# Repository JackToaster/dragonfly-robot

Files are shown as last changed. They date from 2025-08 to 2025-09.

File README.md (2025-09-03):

# Dragonfly Robot
This repository contains hardware and firmware files for a flight controller & 4-channel servo driver, intended for my dragonfly ornithopter robot.

## Robot hardware
The robot is built from components 3d printed out of lightweight PLA and pulltruded carbon fiber rods, with two standard 3.7g RC servos actuating each wing.
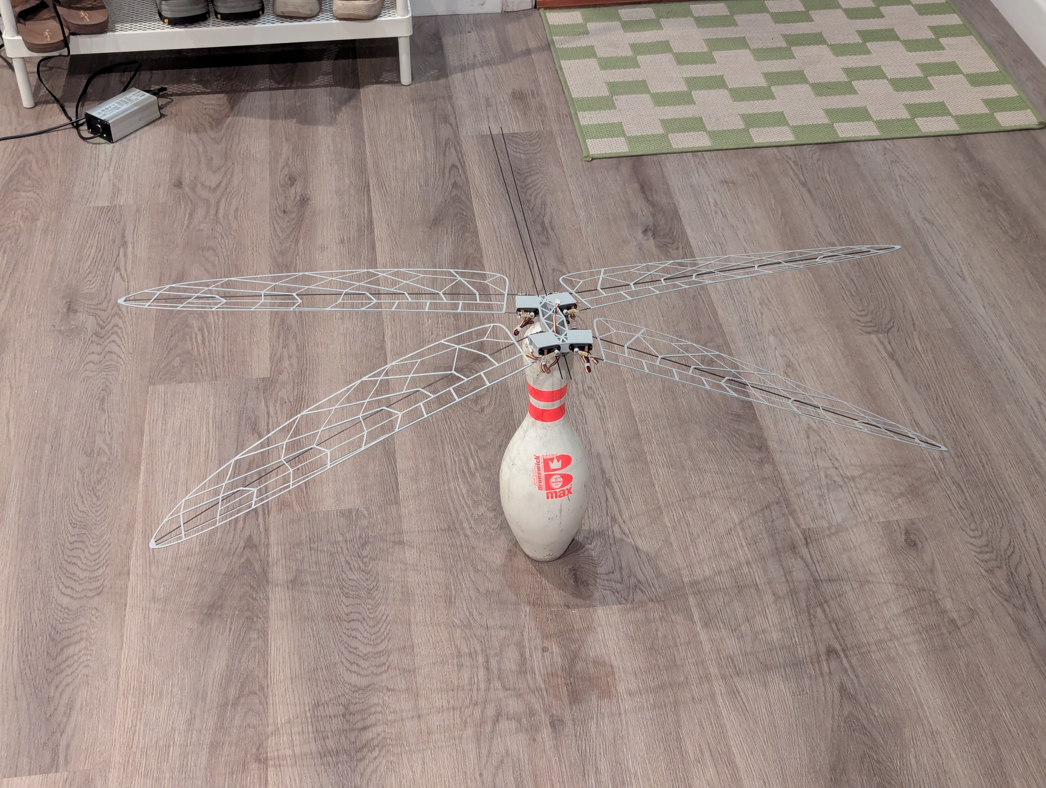
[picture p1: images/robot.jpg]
Dragonfly robot


## PCB
The flight controlelr hardware is based on the WCH CH32V203, a low-cost RISC-V microcontroller.
Motor drives use the TI DRV8212 full-bridge driver and INA199 current sense amplifier for current feedback.
Each controller drives one pair of wings (four actuators). The controllers for each wing pair communicate with each other via I2C. An I2C IMU (MPU6050/MPU9250) is used for attitude control, and an RC receiver is connected over a serial link via the CRSF protocol.
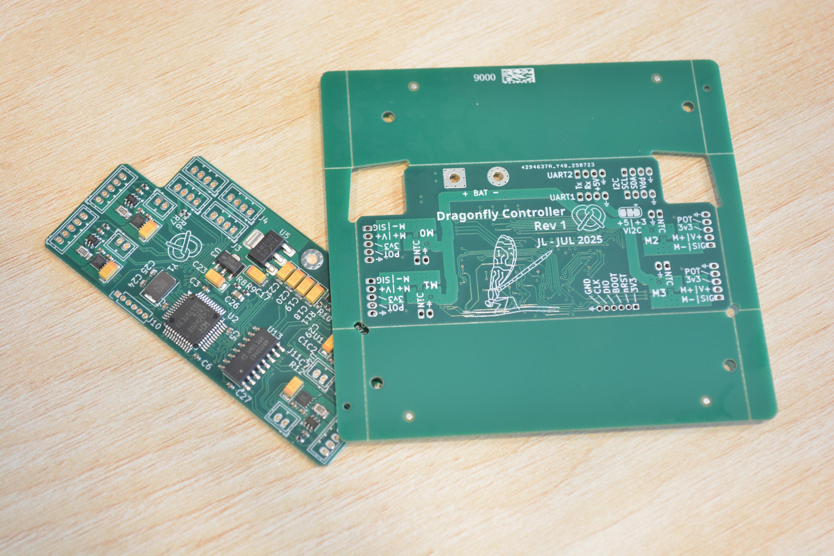
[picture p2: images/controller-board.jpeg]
Dragonfly robot controller PCB


## Firmware
The firmware in this repository utilizes CNLohr's [CH32Fun](https://github.com/cnlohr/ch32fun) framework for register mapping and hardware initialization functionality.

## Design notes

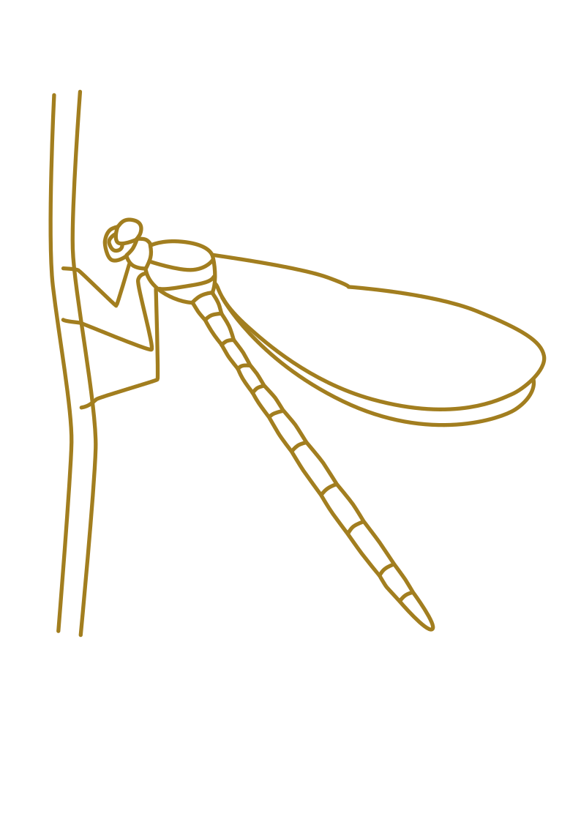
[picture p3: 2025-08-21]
servo-drive/dragonfly.png

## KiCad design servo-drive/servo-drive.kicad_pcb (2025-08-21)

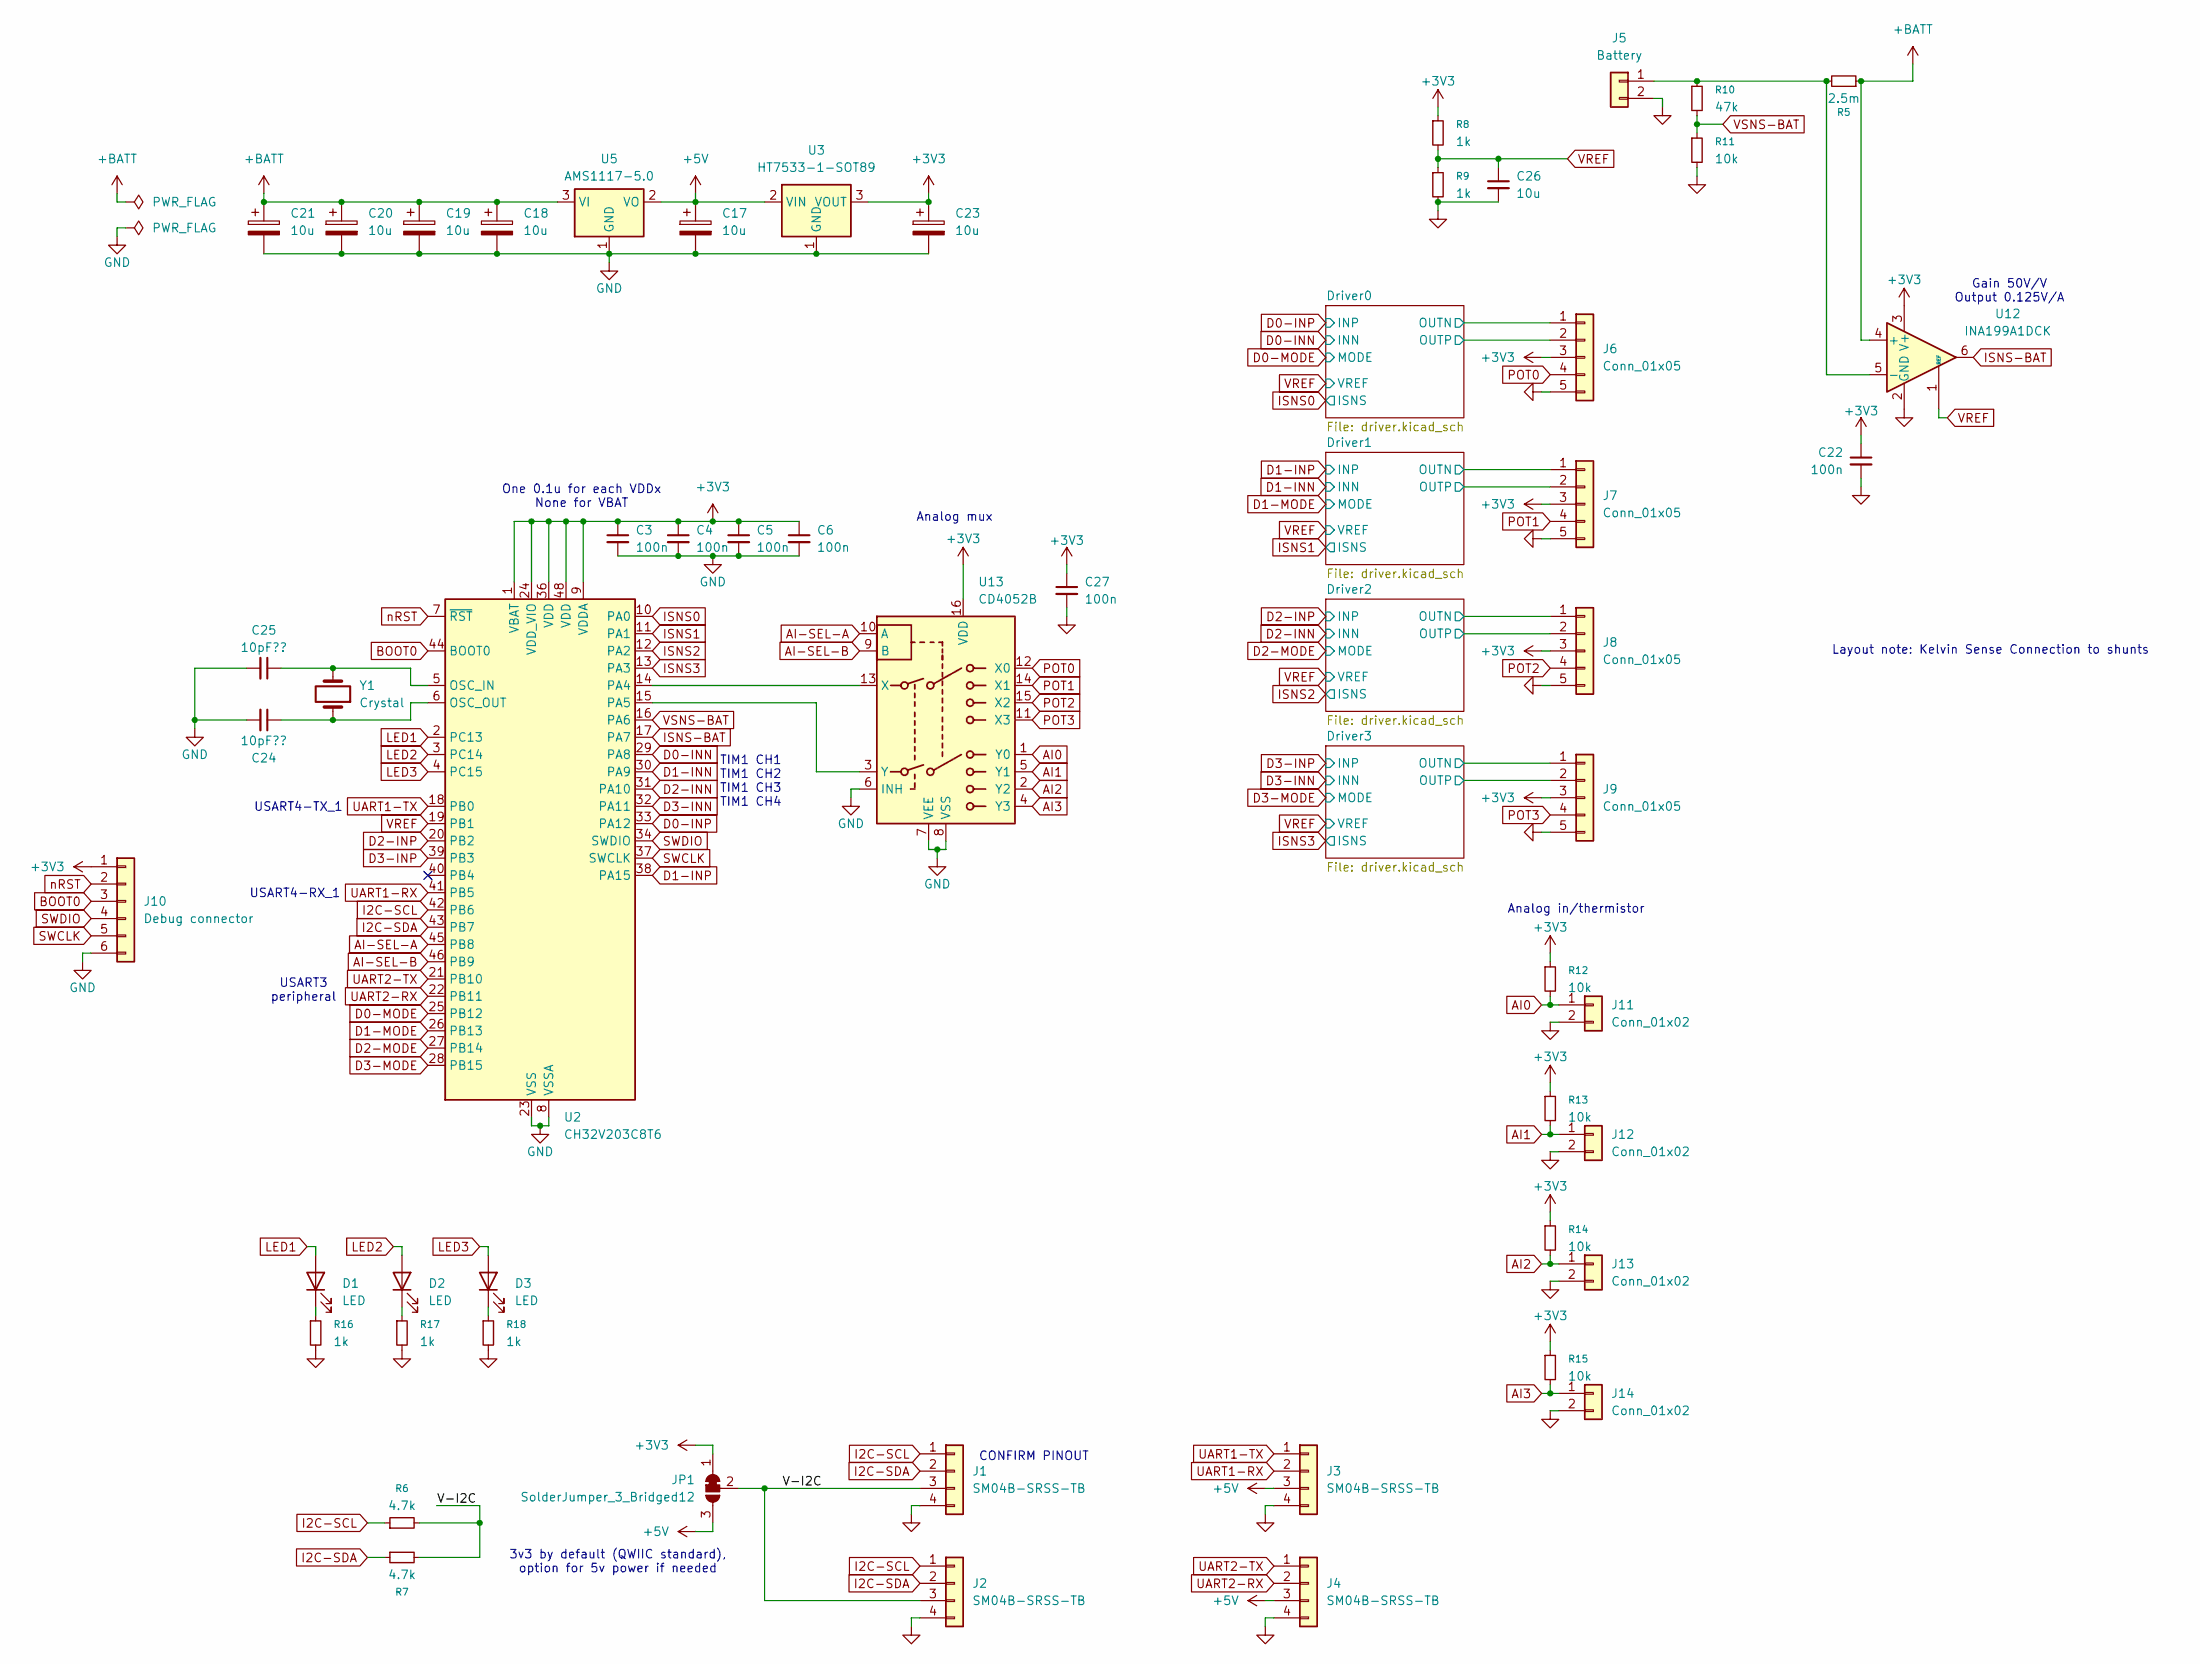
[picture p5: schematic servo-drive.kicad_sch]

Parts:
C3, C4, C5, C6, C22, C27: 100n; C_0402_1005Metric; LCSC C307331
C17, C18, C19, C20, C21, C23: 10u; CP_EIA-3216-18_Kemet-A; LCSC C7171
C24, C25: 10pF??; C_0402_1005Metric; LCSC C32949
C26: 10u; C_0603_1608Metric; LCSC C19702
D1, D2, D3: LED; LED_0603_1608Metric_Pad1.05x0.95mm_HandSolder
J1, J2, J3, J4: SM04B-SRSS-TB; JST_ZH_B4B-ZR_1x04_P1.50mm_Vertical
J5: Battery; SolderWire-1sqmm_1x02_P7.8mm_D1.4mm_OD3.9mm
J6, J7, J8, J9: Conn_01x05; JST_ZH_B5B-ZR_1x05_P1.50mm_Vertical
J10: Debug connector; PinHeader_1x06_P1.27mm_Vertical
J11, J12, J13, J14: Conn_01x02; JST_ZH_B2B-ZR_1x02_P1.50mm_Vertical
JP1: SolderJumper_3_Bridged12; SolderJumper-3_P1.3mm_Bridged12_RoundedPad1.0x1.5mm
R5: 2.5m; R_0805_2012Metric; LCSC C728266
R6, R7: 4.7k; R_0402_1005Metric; LCSC C25900
R8, R9, R16, R17, R18: 1k; R_0402_1005Metric; LCSC C11702
R10: 47k; R_0402_1005Metric; LCSC C25792
R11, R12, R13, R14, R15: 10k; R_0402_1005Metric; LCSC C25744
U2: CH32V203C8T6; LQFP-48_7x7mm_P0.5mm; LCSC C3001172
U3: HT7533-1-SOT89; SOT-89-3; LCSC C14289
U5: AMS1117-5.0; SOT-223-3_TabPin2; LCSC C6187
U12: INA199A1DCK; SOT-363_SC-70-6; LCSC C2653849
U13: CD4052B; SOIC-16_3.9x9.9mm_P1.27mm; LCSC C6521
Y1: Crystal; Crystal_SMD_5032-2Pin_5.0x3.2mm; LCSC C115962

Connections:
+3V3: C3.1, C4.1, C5.1, C6.1, C22.1, C23.1, C27.1, J6.3, J7.3, J8.3, J9.3, J10.1, JP1.1 (A), R8.1, R12.1, R13.1, R14.1, R15.1, U2.1 (VBAT), U2.9 (VDDA), U2.24 (VDD_VIO), U2.36 (VDD), U2.48 (VDD), U3.3 (VOUT), U12.3 (V+), U13.16 (VDD); also elsewhere on the board
+5V: C17.1, J3.3, J4.3, JP1.3 (B), U3.2 (VIN), U5.2 (VO)
+BATT: C18.1, C19.1, C20.1, C21.1, R5.1, U5.3 (VI), U12.4 (+); also elsewhere on the board
/Driver0/OUTN: J6.1; also elsewhere on the board
/Driver0/OUTP: J6.2; also elsewhere on the board
/Driver1/OUTN: J7.1; also elsewhere on the board
/Driver1/OUTP: J7.2; also elsewhere on the board
/Driver2/OUTN: J8.1; also elsewhere on the board
/Driver2/OUTP: J8.2; also elsewhere on the board
/Driver3/OUTN: J9.1; also elsewhere on the board
/Driver3/OUTP: J9.2; also elsewhere on the board
/V-I2C: J1.3, J2.3, JP1.2 (C), R6.2, R7.2
AI0: J11.1, R12.2, U13.1 (Y0)
AI1: J12.1, R13.2, U13.5 (Y1)
AI2: J13.1, R14.2, U13.2 (Y2)
AI3: J14.1, R15.2, U13.4 (Y3)
AI-SEL-A: U2.45 (PB8), U13.10 (A)
AI-SEL-B: U2.46 (PB9), U13.9 (B)
BOOT0: J10.3, U2.44 (BOOT0)
D0-INN: U2.29 (PA8); also elsewhere on the board
D0-INP: U2.33 (PA12); also elsewhere on the board
D0-MODE: U2.25 (PB12); also elsewhere on the board
D1-INN: U2.30 (PA9); also elsewhere on the board
D1-INP: U2.38 (PA15); also elsewhere on the board
D1-MODE: U2.26 (PB13); also elsewhere on the board
D2-INN: U2.31 (PA10); also elsewhere on the board
D2-INP: U2.20 (PB2); also elsewhere on the board
D2-MODE: U2.27 (PB14); also elsewhere on the board
D3-INN: U2.32 (PA11); also elsewhere on the board
D3-INP: U2.39 (PB3); also elsewhere on the board
D3-MODE: U2.28 (PB15); also elsewhere on the board
GND: C3.2, C4.2, C5.2, C6.2, C17.2, C18.2, C19.2, C20.2, C21.2, C22.2, C23.2, C24.2, C25.2, C26.2, C27.2, J1.4, J2.4, J3.4, J4.4, J5.2, J6.5, J7.5, J8.5, J9.5, J10.6, J11.2, J12.2, J13.2, J14.2, R9.2, R11.2, R16.2, R17.2, R18.2, U2.8 (VSSA), U2.23 (VSS), U2.35 (VSS), U2.47 (VSS), U3.1 (GND), U5.1 (GND), U12.2 (GND), U13.6 (INH), U13.7 (VEE), U13.8 (VSS); also elsewhere on the board
I2C-SCL: J1.1, J2.1, R6.1, U2.42 (PB6)
I2C-SDA: J1.2, J2.2, R7.1, U2.43 (PB7)
ISNS0: U2.10 (PA0); also elsewhere on the board
ISNS1: U2.11 (PA1); also elsewhere on the board
ISNS2: U2.12 (PA2); also elsewhere on the board
ISNS3: U2.13 (PA3); also elsewhere on the board
ISNS-BAT: U2.17 (PA7), U12.6
LED1: D1.2 (A), U2.2 (PC13)
LED2: D2.2 (A), U2.3 (PC14)
LED3: D3.2 (A), U2.4 (PC15)
unnamed: D1.1 (K), R16.1
unnamed: D2.1 (K), R17.1
unnamed: D3.1 (K), R18.1
unnamed: J5.1, R5.2, R10.1, U12.5 (-)
unnamed: C25.1, U2.5 (OSC_IN), Y1.2
unnamed: C24.1, U2.6 (OSC_OUT), Y1.1
unnamed: U2.14 (PA4), U13.13 (X)
unnamed: U2.15 (PA5), U13.3 (Y)
POT0: J6.4, U13.12 (X0)
POT1: J7.4, U13.14 (X1)
POT2: J8.4, U13.15 (X2)
POT3: J9.4, U13.11 (X3)
SWCLK: J10.5, U2.37 (SWCLK)
SWDIO: J10.4, U2.34 (SWDIO)
UART1-RX: J3.2, U2.41 (PB5)
UART1-TX: J3.1, U2.18 (PB0)
UART2-RX: J4.2, U2.22 (PB11)
UART2-TX: J4.1, U2.21 (PB10)
VREF: C26.1, R8.2, R9.1, U2.19 (PB1), U12.1 (REF); also elsewhere on the board
VSNS-BAT: R10.2, R11.1, U2.16 (PA6)
nRST: J10.2, U2.7 (~RST)

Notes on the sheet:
Analog mux
USART4-TX_1
Analog in/thermistor
USART4-RX_1
Gain 50V/V Output 0.125V/A
Layout note: Kelvin Sense Connection to shunts
CONFIRM PINOUT
One 0.1u for each VDDx None for VBAT
3v3 by default (QWIIC standard), option for 5v power if needed
USART3 peripheral
TIM1 CH1 TIM1 CH2 TIM1 CH3 TIM1 CH4

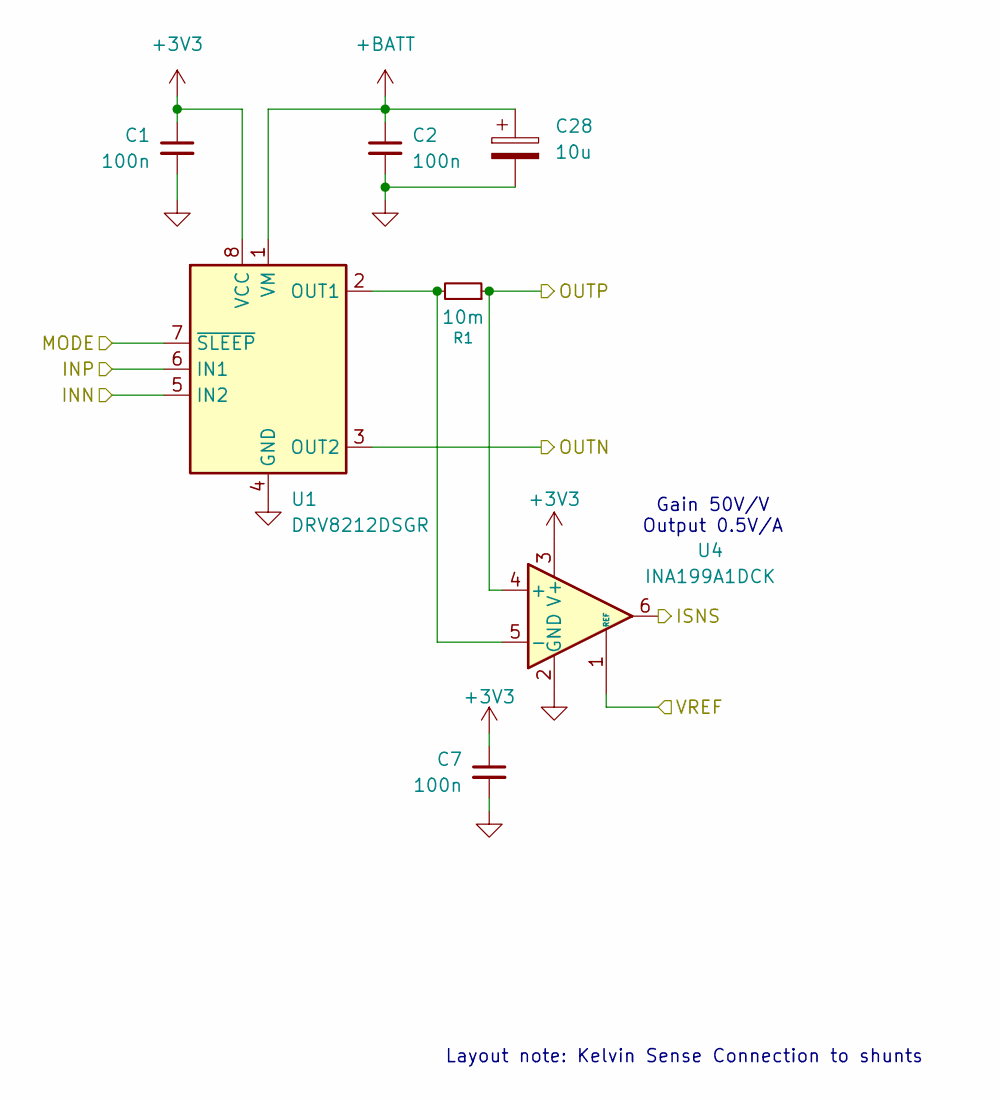
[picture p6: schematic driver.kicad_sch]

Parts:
C1, C2, C7: 100n; C_0402_1005Metric; LCSC C307331
C28: 10u; CP_EIA-3216-18_Kemet-A; LCSC C7171
R1: 10m; R_0805_2012Metric; LCSC C104574
U1: DRV8212DSGR; WSON-8-1EP_2x2mm_P0.5mm_EP0.9x1.6mm_ThermalVias; LCSC C2843766
U4: INA199A1DCK; SOT-363_SC-70-6; LCSC C2653849

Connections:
+3V3: C1.1, C7.1, U1.8 (VCC), U4.3 (V+); also elsewhere on the board
+BATT: C2.1, C28.1, U1.1 (VM); also elsewhere on the board
/Driver0/OUTN: U1.3 (OUT2); also elsewhere on the board
/Driver0/OUTP: R1.1, U4.4 (+); also elsewhere on the board
D0-INN: U1.5 (IN2); also elsewhere on the board
D0-INP: U1.6 (IN1); also elsewhere on the board
D0-MODE: U1.7 (~SLEEP); also elsewhere on the board
GND: C1.2, C2.2, C7.2, C28.2, U1.4 (GND), U1.9 (GND), U4.2 (GND); also elsewhere on the board
ISNS0: U4.6; also elsewhere on the board
unnamed: R1.2, U1.2 (OUT1), U4.5 (-)
VREF: U4.1 (REF); also elsewhere on the board

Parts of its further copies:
C8, C9, C10, C11, C12, C13, C14, C15, C16: 100n; C_0402_1005Metric; LCSC C307331
C29, C30, C31: 10u; CP_EIA-3216-18_Kemet-A; LCSC C7171
R2, R3, R4: 10m; R_0805_2012Metric; LCSC C104574
U6, U8, U10: DRV8212DSGR; WSON-8-1EP_2x2mm_P0.5mm_EP0.9x1.6mm_ThermalVias; LCSC C2843766
U7, U9, U11: INA199A1DCK; SOT-363_SC-70-6; LCSC C2653849

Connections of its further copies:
+3V3: C8.1, C10.1, C11.1, C13.1, C14.1, C16.1, U6.8 (VCC), U7.3 (V+), U8.8 (VCC), U9.3 (V+), U10.8 (VCC), U11.3 (V+); also elsewhere on the board
+BATT: C9.1, C12.1, C15.1, C29.1, C30.1, C31.1, U6.1 (VM), U8.1 (VM), U10.1 (VM); also elsewhere on the board
/Driver1/OUTN: U6.3 (OUT2); also elsewhere on the board
/Driver1/OUTP: R2.1, U7.4 (+); also elsewhere on the board
/Driver2/OUTN: U8.3 (OUT2); also elsewhere on the board
/Driver2/OUTP: R3.1, U9.4 (+); also elsewhere on the board
/Driver3/OUTN: U10.3 (OUT2); also elsewhere on the board
/Driver3/OUTP: R4.1, U11.4 (+); also elsewhere on the board
D1-INN: U6.5 (IN2); also elsewhere on the board
D1-INP: U6.6 (IN1); also elsewhere on the board
D1-MODE: U6.7 (~SLEEP); also elsewhere on the board
D2-INN: U8.5 (IN2); also elsewhere on the board
D2-INP: U8.6 (IN1); also elsewhere on the board
D2-MODE: U8.7 (~SLEEP); also elsewhere on the board
D3-INN: U10.5 (IN2); also elsewhere on the board
D3-INP: U10.6 (IN1); also elsewhere on the board
D3-MODE: U10.7 (~SLEEP); also elsewhere on the board
GND: C8.2, C9.2, C10.2, C11.2, C12.2, C13.2, C14.2, C15.2, C16.2, C29.2, C30.2, C31.2, U6.4 (GND), U6.9 (GND), U7.2 (GND), U8.4 (GND), U8.9 (GND), U9.2 (GND), U10.4 (GND), U10.9 (GND), U11.2 (GND); also elsewhere on the board
ISNS1: U7.6; also elsewhere on the board
ISNS2: U9.6; also elsewhere on the board
ISNS3: U11.6; also elsewhere on the board
unnamed: R2.2, U6.2 (OUT1), U7.5 (-)
unnamed: R3.2, U8.2 (OUT1), U9.5 (-)
unnamed: R4.2, U10.2 (OUT1), U11.5 (-)
VREF: U7.1 (REF), U9.1 (REF), U11.1 (REF); also elsewhere on the board

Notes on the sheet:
Gain 50V/V Output 0.5V/A
Layout note: Kelvin Sense Connection to shunts

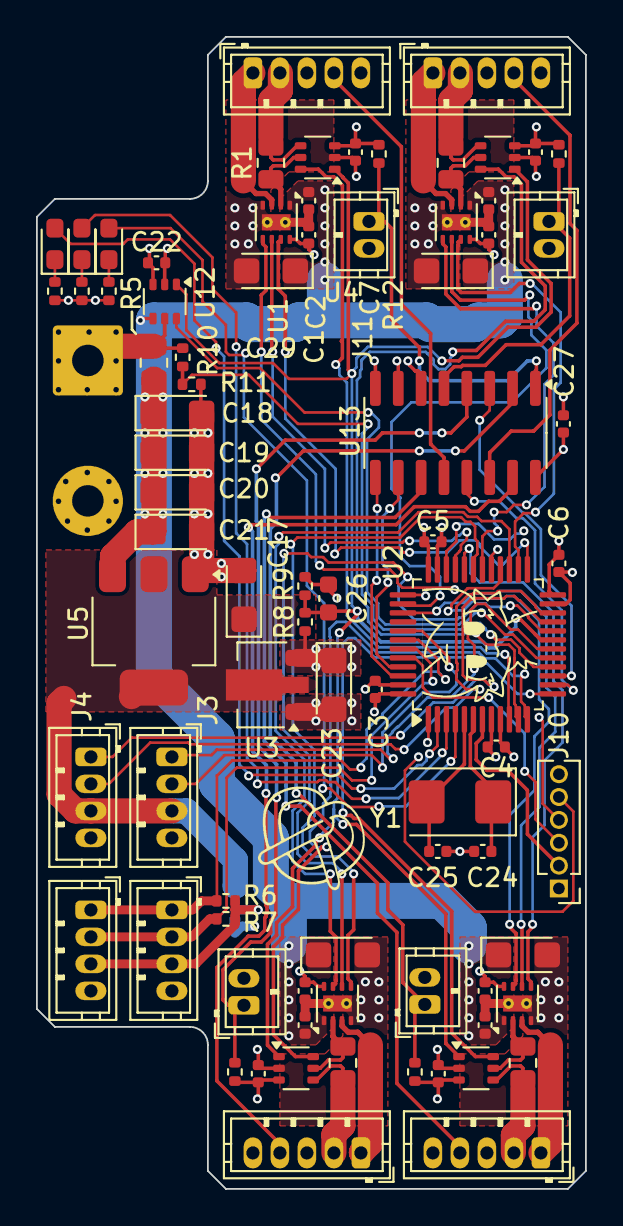
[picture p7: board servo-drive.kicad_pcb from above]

Board: 4 copper layers, 30.5 x 64.0 mm, 81 parts (1 on the bottom side), 67 nets.

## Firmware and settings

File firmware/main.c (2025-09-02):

#include "ch32fun.h"
#include <stdint.h>
#include <stdio.h>
#include "ch32v20xhw.h"

#include "main.h"
#include "led_status.h"
#include "adc.h"
#include "serial.h"
#include "systick.h"
#include "motor.h"
#include "crsf.h"

// Debug printf
uint32_t count;

int last = 0;
void handle_debug_input( int numbytes, uint8_t * data )
{
	last = data[0];
	count += numbytes;
}


// LED indicator state
LedStateT status_led_state;

uint32_t get_vbat( void ){
	return (uint32_t) adc_state.vsns_bat * ADC_VDD_mV / ADC_COUNTS * 57 / 10 ;
}


uint8_t adc_sel_no = 0;
void system_update( void ) {


	led_status_process(&status_led_state);
	// start polling new adc data
	adc_poll_dma();
	adc_wait_for_data();
	// read last data
	adc_process_data();

	motor_update(); // update motor control loops

	++adc_sel_no;
	if(adc_sel_no >= 4) { adc_sel_no = 0; }
	adc_ai_select(adc_sel_no);
}

int main()
{
	SystemInit();

	// APB2 clock /2 (72MHz)
	RCC->CFGR0 |= RCC_PPRE2_DIV2;

	funGpioInitAll(); // Enable GPIOs

	// MCO for clock debugging
	// RCC->CFGR0 |= RCC_CFGR0_MCO_SYSCLK;


	funPinMode(AI_SEL_A, GPIO_CFGLR_OUT_10Mhz_PP);
	funPinMode(AI_SEL_B, GPIO_CFGLR_OUT_10Mhz_PP);

	// initializing peripherals
	status_led_state = led_status_init();

	crc_init();

	// Serial
	printf("starting serial...\n");
	serial_init();
	dma_uart_setup();
	printf("Serial up\n");

	// ADC
	printf("starting ADC...\n");
	adc_init();
	printf("ADC up\n");

	motor_init();

	// enable systick
	systick_init();
	uint8_t duty = 100;

	uint32_t last_t;
	uint32_t last_pos;

	for(uint8_t i = 0; i < N_MOTORS; ++i) {
		// motors[i].duty_cap = MOTOR_DUTY_MAX / 3; // 33% duty limit to avoid burning out servos while testing
	}

	wakeup_motors();
	// set_position(&motors[3], 1500);

	while(1)
	{
		Delay_Us(systick_remaining_us()); // wait for next tick

		// printf("M3 P:%d\n", adc_state.pot[3]);
		system_update();
	

		// if(millis() % 2000 == 0) {
		// 	set_position(&motors[3], 1900);
		// }
		// if(millis() % 2000 == 1000) {
		// 	set_position(&motors[3], 2100);
		// }
		// printf("%d\n", adc_state.pot[3]);
		// https://github.com/crsf-wg/crsf/wiki/Message-Format
		uint8_t bytes;
		while((bytes = bytes_available(&uart3_rxbuf)) >= 4) { // minimum size for CSRF message is 4 bytes
			uint8_t sync = peek(&uart3_rxbuf);
			if(sync == 0xC8 || sync == 0xEE) { // check for CRSF Sync byte
				uint8_t* header = peek_n(&uart3_rxbuf, 3);
				uint8_t msg_len = header[1] + 2; // message length is LEN+2
				if(msg_len > 64) {
					printf("I\n");//NVALID sync %x len %d :(((\n", sync, msg_len);
					
					read_data(&uart3_rxbuf, 1); // discard byte
					continue;
				}
				uint8_t msg_type = header[2];
				if(bytes >= msg_len) {
					// printf("msg! len %d type %x\n", msg_len, msg_type);
					uint8_t* message = read_data(&uart3_rxbuf, msg_len);
					uint8_t crc = crc8x_fast(0, &message[2], msg_len - 3);
					uint8_t msg_crc = message[msg_len - 1];
					if(crc != msg_crc) {
						printf("crc er %x %x\n", crc, msg_crc);
						continue;
					}
					if(msg_type == 0x16) { // RC channels packed
						
						// printf("Computed %x msg %x\n", crc, msg_crc);
						struct crsf_channels_s* channels = (struct crsf_channels_s*) &message[3];


						// printf("Channels %u %u %u %u %u %u %u %u %u %u %u %u %u %u %u %u\n", channels->ch0,channels->ch1,channels->ch2,channels->ch3,channels->ch4,channels->ch5,channels->ch6,channels->ch7,channels->ch8,channels->ch9,channels->ch10,channels->ch11,channels->ch12,channels->ch13,channels->ch14,channels->ch15);
						// set_duty_pct(&motors[3], (((int32_t)channels->ch0) - 992) / 6);
						set_position(&motors[3], (int32_t)channels->ch0);
					}
				} else {
					break;
				}
			} else {
				// printf(":( %d\n", uart3_rxbuf.overrun);
				read_data(&uart3_rxbuf, 1); // discard byte
			}
		}
	}
}

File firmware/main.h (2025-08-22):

#pragma once
#include "adc.h"


#define ADC_VDD_mV 3300
#define MOTOR_ISNS_GAIN (1000/500) // mAmps/mVolt
#define BATTERY_ISNS_GAIN (1000/125) // mAmps/mVolt
#define BATTERY_VSNS_GAIN (57000/10) // mVolt/volt

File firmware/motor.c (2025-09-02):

#include "motor.h"
#include "adc.h"
#include "ch32fun.h"
#include "ch32v20xhw.h"
#include "systick.h"
#include <stdlib.h>

MotorCtrlT motors[N_MOTORS];

void motor_init( void ) {
	// init motors struct
	for(uint8_t i = 0; i < N_MOTORS; ++i){
		motors[i].duty = 0;
		motors[i].current_setpoint = 0;
		motors[i].current_integrator = 0;

		motors[i].position_setpoint = 2048; // midpoint
		motors[i].duty_cap = MOTOR_DUTY_MAX;
		motors[i].mode = MOTOR_DISABLED;
	}
	// motor pins/buffers
	motors[0].duty_buffer = &(TIM1->CH1CVR);
	motors[0].dir_pin = MOTOR_D0_DIR;

	motors[1].duty_buffer = &(TIM1->CH2CVR);
	motors[1].dir_pin = MOTOR_D2_DIR;

	motors[2].duty_buffer = &(TIM1->CH3CVR);
	motors[2].dir_pin = MOTOR_D2_DIR;

	motors[3].duty_buffer = &(TIM1->CH4CVR);
	motors[3].dir_pin = MOTOR_D3_DIR;

	// setup TIM1
	// enable TIM1
	RCC->APB2PCENR |= RCC_APB2Periph_TIM1;

	// Reset TIM1 to init all regs
	RCC->APB2PRSTR |= RCC_APB2Periph_TIM1;
	RCC->APB2PRSTR &= ~RCC_APB2Periph_TIM1;

	// CTLR1: default is up, events generated, edge align
	// SMCFGR: default clk input is CK_INT
	
	// Prescaler 
	// Using APB2 Bus x2 (72MHz x2 = 144MHz)
	TIM1->PSC = 0x0000;
	
	// Auto Reload - sets period
	TIM1->ATRLR = MOTOR_DUTY_MAX;
	
	// Reload immediately
	TIM1->SWEVGR |= TIM_UG;

	
	// Enable CH1-4 output, default polarity (High for 0-CCR, low after)
	TIM1->CCER |= TIM_CC1E | TIM_CC2E | TIM_CC3E | TIM_CC4E;
	
	// CH1/2 Mode is output, PWM1 (CC1S = 00, OC1M = 110)
	TIM1->CHCTLR1 |= TIM_OC1M_2 | TIM_OC1M_1 | TIM_OC2M_2 | TIM_OC2M_1;
	
	// CH3/4 Mode is output, PWM1 (CC1S = 00, OC1M = 110)
	TIM1->CHCTLR2 |= TIM_OC3M_2 | TIM_OC3M_1 | TIM_OC4M_2 | TIM_OC4M_1;
	
	// Set the Capture Compare Register value to 0 initially
	TIM1->CH1CVR = 0;
	TIM1->CH2CVR = 0;
	TIM1->CH3CVR = 0;
	TIM1->CH4CVR = 0;
	
	// Enable TIM1 outputs
	TIM1->BDTR |= TIM_MOE;
	
	// Enable TIM1
	TIM1->CTLR1 |= TIM_CEN;

	// Setup mode pins
	funPinMode( MOTOR_D0_MODE, GPIO_Speed_10MHz | GPIO_CNF_OUT_PP );
	funPinMode( MOTOR_D1_MODE, GPIO_Speed_10MHz | GPIO_CNF_OUT_PP );
	funPinMode( MOTOR_D2_MODE, GPIO_Speed_10MHz | GPIO_CNF_OUT_PP );
	funPinMode( MOTOR_D3_MODE, GPIO_Speed_10MHz | GPIO_CNF_OUT_PP );

	// MODE 1 PH/EN
	funDigitalWrite(MOTOR_D0_MODE, 1);
	funDigitalWrite(MOTOR_D1_MODE, 1);
	funDigitalWrite(MOTOR_D2_MODE, 1);
	funDigitalWrite(MOTOR_D3_MODE, 1);


	// set up enable pins (these get PWM'd)
	funPinMode( MOTOR_D0_EN, GPIO_Speed_10MHz | GPIO_CNF_OUT_PP_AF );
	funPinMode( MOTOR_D1_EN, GPIO_Speed_10MHz | GPIO_CNF_OUT_PP_AF );
	funPinMode( MOTOR_D2_EN, GPIO_Speed_10MHz | GPIO_CNF_OUT_PP_AF );
	funPinMode( MOTOR_D3_EN, GPIO_Speed_10MHz | GPIO_CNF_OUT_PP_AF );


	// Dir pins
	funPinMode( MOTOR_D0_DIR, GPIO_Speed_10MHz | GPIO_CNF_OUT_PP );
	funPinMode( MOTOR_D1_DIR, GPIO_Speed_10MHz | GPIO_CNF_OUT_PP );
	funPinMode( MOTOR_D2_DIR, GPIO_Speed_10MHz | GPIO_CNF_OUT_PP );
	funPinMode( MOTOR_D3_DIR, GPIO_Speed_10MHz | GPIO_CNF_OUT_PP );

	funDigitalWrite(MOTOR_D3_DIR, 0);
	funDigitalWrite(MOTOR_D3_DIR, 0);
	funDigitalWrite(MOTOR_D3_DIR, 0);
	funDigitalWrite(MOTOR_D3_DIR, 0);


}

uint8_t ditherer = 0;
void set_from_duty(MotorCtrlT * motor) {
	uint32_t pos_duty = abs(motor->duty);

	pos_duty += MOTOR_DUTY_MIN;  // duties less than this will make the DRV8212 fall asleep :'(
	// this means you can't go below 4% duty at 10kHz, 8% at 20kHz

	if(pos_duty > motor->duty_cap) {
		pos_duty = motor->duty_cap;
	}
	
	funDigitalWrite(motor->dir_pin, motor->duty > 0);
	*motor->duty_buffer = pos_duty;
}
void motor_update( void ) {
	ditherer = !ditherer; // toggle each time
	for(uint8_t i = 0; i < N_MOTORS; ++i) {
		if(motors[i].mode == MOTOR_DISABLED) {
			*motors[i].duty_buffer = 0; // will need to wake up again...
		}else if(motors[i].mode == MOTOR_DUTY_CYCLE) {
			set_from_duty(&motors[i]);
		}else if(motors[i].mode == MOTOR_CURRENT_CONTROL) { // TODO Current sensing borken :'(((
			int32_t current_feedback = adc_state.isns_motor[i]; // read & convert to int32

			#ifdef CURRENT_FEEDBACK_INVERTED
			current_feedback = -current_feedback; // invert if necessary
			#endif
			
			int32_t current_error = motors[i].current_setpoint - current_feedback;

			int32_t current_p = current_error * CURRENT_kP; // proportional term
			
			//integral term
			motors[i].current_integrator += current_error;

			int32_t current_i = motors[i].current_integrator * CURRENT_kI;
			if(current_i > CURRENT_GAIN_SCALE) { // anti-windup past limits of control
				motors[i].current_integrator = CURRENT_GAIN_SCALE / CURRENT_kI;
			} else if(current_i < -CURRENT_GAIN_SCALE) {
				motors[i].current_integrator = -(CURRENT_GAIN_SCALE / CURRENT_kI);
			}

			int32_t demand = current_p + current_i;
			motors[i].duty = (demand * MOTOR_DUTY_MAX) / CURRENT_GAIN_SCALE;
			set_from_duty(&motors[i]);
		}else if(motors[i].mode == MOTOR_POSITION_CONTROL) {
			int32_t position = adc_state.pot[i]; // read & convert to int32
			
			int32_t pos_error = motors[i].position_setpoint - position;

			int32_t pos_p = pos_error * POSITION_kP; // proportional term
			
			int32_t delta = pos_error - motors[i].prev_pos_err;

			int32_t pos_d = delta * POSITION_kD;
			//integral term
			motors[i].position_integrator += pos_error;

			int32_t position_i = motors[i].position_integrator * POSITION_kI;
			if(position_i > POSITION_GAIN_SCALE) { // anti-windup past limits of control
				motors[i].position_integrator = POSITION_GAIN_SCALE / POSITION_kI;
			} else if(position_i < -POSITION_GAIN_SCALE) {
				motors[i].position_integrator = -(POSITION_GAIN_SCALE / POSITION_kI);
			}

			int32_t demand = pos_p + position_i - pos_d;
			motors[i].duty = (demand * MOTOR_DUTY_MAX) / POSITION_GAIN_SCALE;
			set_from_duty(&motors[i]);
			motors[i].prev_pos_err = pos_error;
		}

	}
}

void wakeup_motors( void ) {
	for(uint8_t i = 0; i < N_MOTORS; ++i) {
		*motors[i].duty_buffer = MOTOR_DUTY_MAX;
	}
	Delay_Ms(2);
	for(uint8_t i = 0; i < N_MOTORS; ++i) {
		*motors[i].duty_buffer = MOTOR_DUTY_MIN;
	}
}

void set_current_mA(MotorCtrlT* motor, int32_t current_mA) {
	motor->mode = MOTOR_CURRENT_CONTROL;
	motor->current_setpoint = current_mA * 1000 / MOTOR_CURRENT_GAIN;
}

void set_position(MotorCtrlT* motor, int32_t setpoint) {
	motor->mode = MOTOR_POSITION_CONTROL;
	motor->position_setpoint = setpoint;
}

void set_duty_pct(MotorCtrlT* motor, int32_t duty_pct) {
	// duty_pct is -100 to +100
	motor->mode = MOTOR_DUTY_CYCLE;
	motor->duty = (duty_pct * MOTOR_DUTY_MAX) / 100; // convert units
}

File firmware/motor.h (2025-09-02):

#pragma once
#include "ch32fun.h"
#include "ch32v20xhw.h"

#define CURRENT_FEEDBACK_INVERTED

#define MOTOR_CURRENT_GAIN 1700 // uA per ADC count, divide by 1000. Theoretically 1.611 but calibrated to 1.7

#define MOTOR_MAX_CURRENT_mA 200
#define MOTOR_DUTY_MAX 14400 // sets 20kHz PWM frequency
#define MOTOR_DUTY_MIN 600 // can't go below this or the motors fall alseep :P

#define CURRENT_GAIN_SCALE 32768 // Gains are 1/8192 of full duty per unit
#define CURRENT_kP 1
#define CURRENT_kI 500

#define MOTOR_KV 2750 // units/sec/V

#define POSITION_GAIN_SCALE 32768
#define POSITION_kP 50
#define POSITION_kI 0
#define POSITION_kD 0

#define MOTOR_D0_MODE PB12
#define MOTOR_D1_MODE PB13
#define MOTOR_D2_MODE PB14
#define MOTOR_D3_MODE PB15

#define MOTOR_D0_DIR PA12
#define MOTOR_D1_DIR PA15
#define MOTOR_D2_DIR PB2
#define MOTOR_D3_DIR PB3

#define MOTOR_D0_EN PA8
#define MOTOR_D1_EN PA9
#define MOTOR_D2_EN PA10
#define MOTOR_D3_EN PA11

#define N_MOTORS 4

typedef enum MotorControlMode {
	MOTOR_DISABLED=0,
	MOTOR_DUTY_CYCLE=1,
	MOTOR_CURRENT_CONTROL=2,
	MOTOR_POSITION_CONTROL=3,
} MotorControlMode;

typedef struct MotorCtrlT {
	MotorControlMode mode;

	uint32_t duty_cap;
	int32_t duty; // -MOTOR_DUTY_MAX to +MOTOR_DUTY_MAX
	volatile uint16_t* duty_buffer; // Buffer to write PWM duty
	uint32_t dir_pin;

	int32_t current_setpoint; // motor current setpoint in ADC counts
	int32_t current_integrator; // integrator for current control loop

	int32_t position_setpoint; // in motor sensor units
	int32_t position_integrator; // integrator for current control loop
	int32_t feedforward_vel; // motor sensor units/sec
	int32_t prev_pos_err;

} MotorCtrlT;

void set_duty_pct(MotorCtrlT* motor, int32_t duty_pct);

void set_current_mA(MotorCtrlT* motor, int32_t current_mA);

void set_position(MotorCtrlT* motor, int32_t setpoint);

extern MotorCtrlT motors[N_MOTORS];

void motor_init( void );

void wakeup_motors( void );

void motor_update( void );

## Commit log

2025-08-22 servo control
2025-08-28 serial working!
    [servo-drive.kicad_sch]
2025-09-01 start crsf/i2c dev
2025-09-02 add crc to crsf decoding, fix adc
    [main.c, motor.c, motor.h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]
